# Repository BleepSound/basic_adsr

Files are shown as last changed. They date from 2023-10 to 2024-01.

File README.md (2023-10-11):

# Basic ADSR

Basic ADSR based on René Schmitz [Fastest envelope in the West](https://www.schmitzbits.de/adsr.html). 

Four pots, one input, one output (just what you need).

On switch to change the time constant of the ADSR. I chose some arbitrary values for the capacitors in my case, but if you want different values, you can adjust them to your needs. 

Just change the values of **C8** and **C9**, which can be either polarized electrolytic or unpolarized capacitors. Just make sure you get the orientation right on the polarized ones.

## Schematics

basic ADSR schematic

## BoM

[See bom](documentation/bom/Basic-ADSR_V1.0--iBoM.html)

## Build Informations

Regular build, I use ceramic capacitors but you can use film/polyester.

:warning: When building modules, always do it in this order (from smallest component to highest):
- diodes
- resistors
- DIP chips
- capacitors (film/ceramic)
- Transistors
- Electrolytic capacitors

To solder the headers, place them and place both PCBs in their final position before fully soldering the pin headers/sockets.

For the next parts, always place them without soldering them on: 
- jacks, pots and switches that go throught the front panel

Once placed, put the front panel in place, then fasten all components to it. Once this is done, you can solder all the remaining components.

## Images

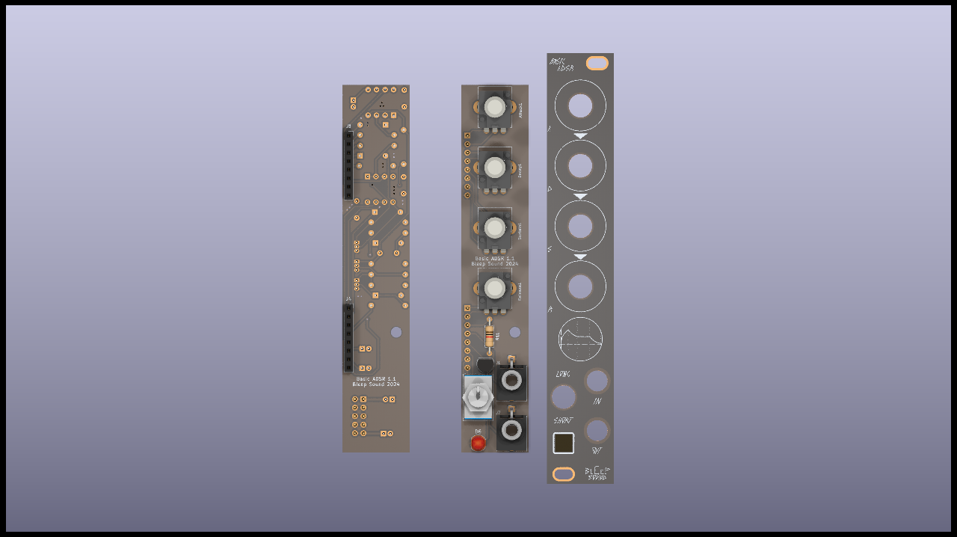
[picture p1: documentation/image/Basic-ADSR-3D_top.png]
3D basic ADSR(front)


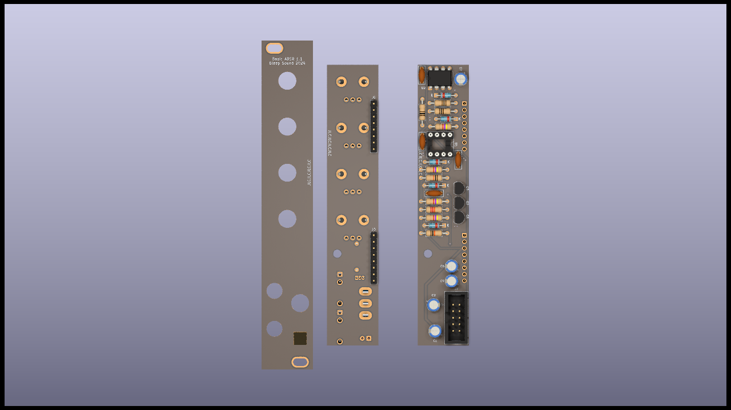
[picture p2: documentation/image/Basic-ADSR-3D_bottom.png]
3D basic ADSR(back)


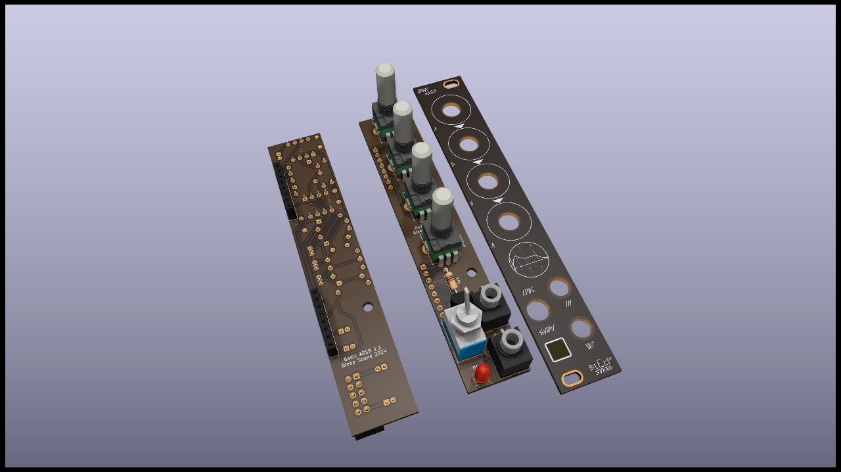
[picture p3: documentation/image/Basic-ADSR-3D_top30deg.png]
3D basic ADSR(iso)


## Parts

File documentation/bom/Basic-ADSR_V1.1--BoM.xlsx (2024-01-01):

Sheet: BoM
Basic-ADSR_V1.1 Bill of Materials
Schematic: | Basic-ADSR | Component Groups: | 23
Variant: | default | Component Count: | 44 (0 SMD/ 44 THT)
Revision: | 1.1 | Fitted Components: | 44 (0 SMD/ 44 THT)
Date: | 2024-01-01 | Number of PCBs: | 1
KiCad Version: | 7.0.7-7.0.7~ubuntu22.04.1 | Total Components: | 44
Row | Description | References | Value | Quantity Per PCB | Comments
1 | Potentiometer | Attack1 Decay1 Release1 | 1M | 3 | Pots
2 | Unpolarized capacitor, small symbol | C5 | 10nF | 1
3 | Unpolarized capacitor, small symbol | C3 C4 C6 | 100nF | 3
4 |  | C8 | 1uF | 1 | Radial electrolytic capacitors, can be changed to any value to change length
5 |  | C9 | 4.7uF | 1 | Radial electrolytic capacitors, can be changed to any value to change length
6 |  | C1 C2 C7 | 10uF | 3 | Radial electrolytic capacitors
7 | Diode | D1 D2 D3 D4 D5 | 1N4148 | 5
8 | Light emitting diode | D6 | Out-LED | 1
9 | Generic connector, single row, 01x08, script generated (kicad-library-utils/schlib/autogen/connector/) | J3 J4 | Conn_Circuit | 2
10 | Generic connector, single row, 01x08, script generated (kicad-library-utils/schlib/autogen/connector/) | J5 J6 | Conn_Jack | 2
11 | Thonkiconn Audio Jack | J1 | In | 1 | Thonkiconn jack
12 | Thonkiconn Audio Jack | J7 | Output | 1 | Thonkiconn jack
13 | Generic connector, single row, 01x10, script generated (kicad-library-utils/schlib/autogen/connector/) | J2 | Power Input | 1
14 | 0.1A Ic, 45V Vce, Small Signal NPN Transistor, TO-92 | Q1 Q2 Q3 Q4 | BC547 (https://www.onsemi.com/pub/Collateral/BC550-D.pdf) | 4 | Can use BC548
15 | Resistor | R7 R8 R10 | 100R | 3
16 | Resistor | R11 | 1k | 1
17 | Resistor | R2 R4 R6 R9 | 4.7k | 4
18 | Resistor | R1 R5 | 10k | 2
19 | Resistor | R3 | 22k | 1
20 | Switch, single pole double throw | SW1 | Length (https://www.taydaelectronics.com/mini-toggle-switch-spdt-on-on.html) | 1 | SPDT On-On Switch
21 | Potentiometer | Sustain1 | 10k | 1 | Pots
22 | Timer, 555 compatible, PDIP-8 | U2 | LM555xN (http://www.ti.com/lit/ds/symlink/lm555.pdf) | 1
23 | Dual Low-Noise JFET-Input Operational Amplifiers, DIP-8/SOIC-8 | U1 | TL072 (http://www.ti.com/lit/ds/symlink/tl071.pdf) | 1

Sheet: Colors
KiCad Fields (default)
Generated Fields
User Fields
Empty Fields

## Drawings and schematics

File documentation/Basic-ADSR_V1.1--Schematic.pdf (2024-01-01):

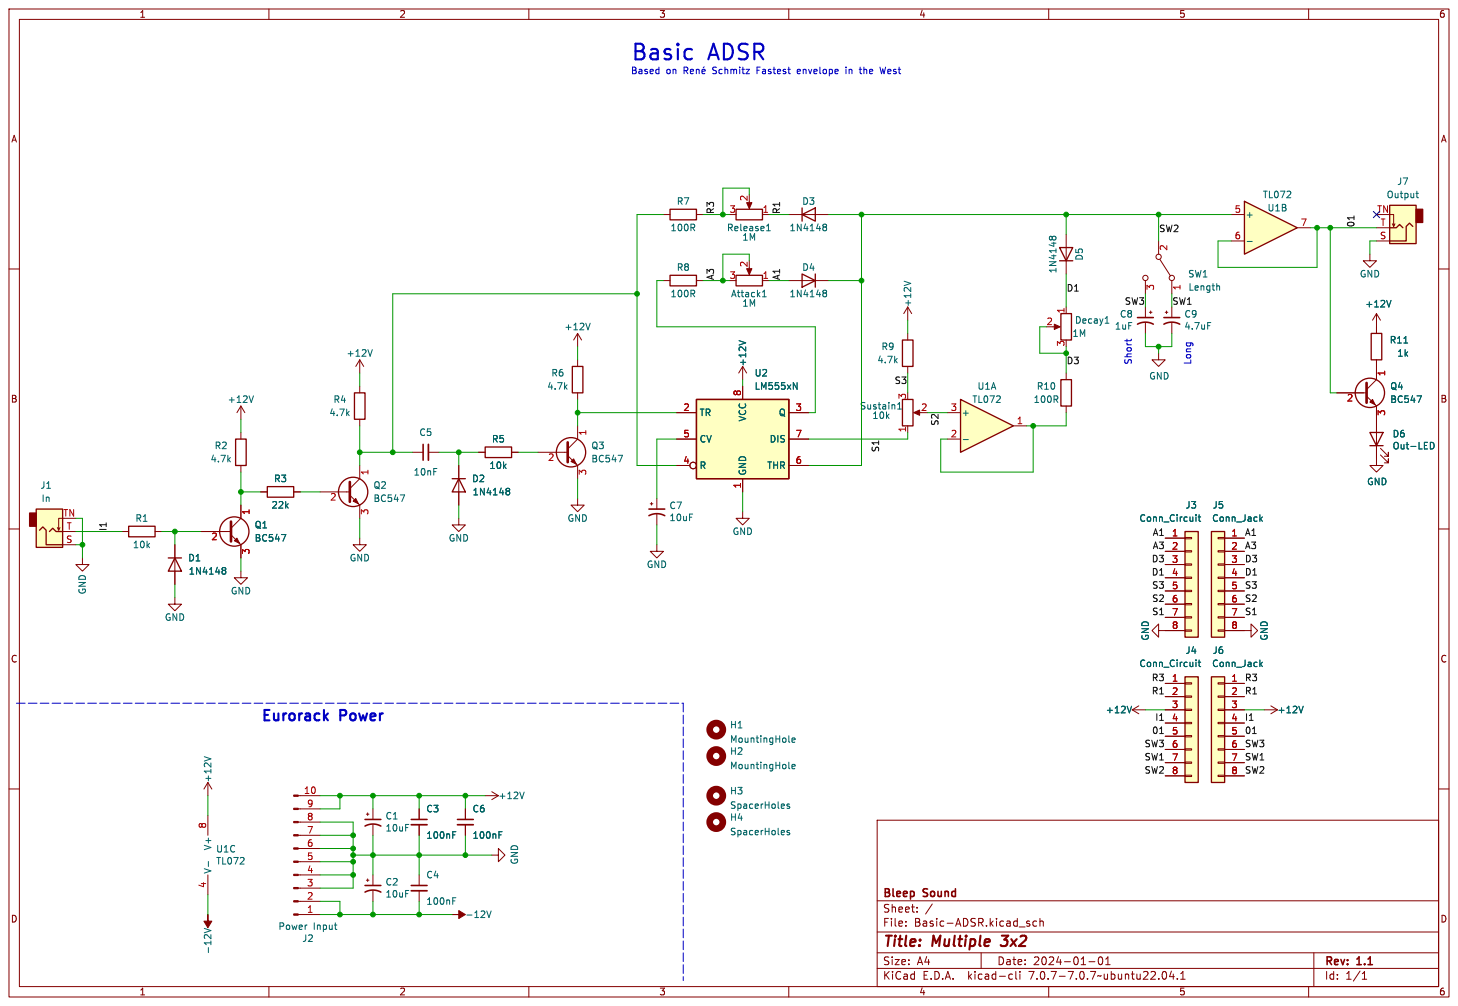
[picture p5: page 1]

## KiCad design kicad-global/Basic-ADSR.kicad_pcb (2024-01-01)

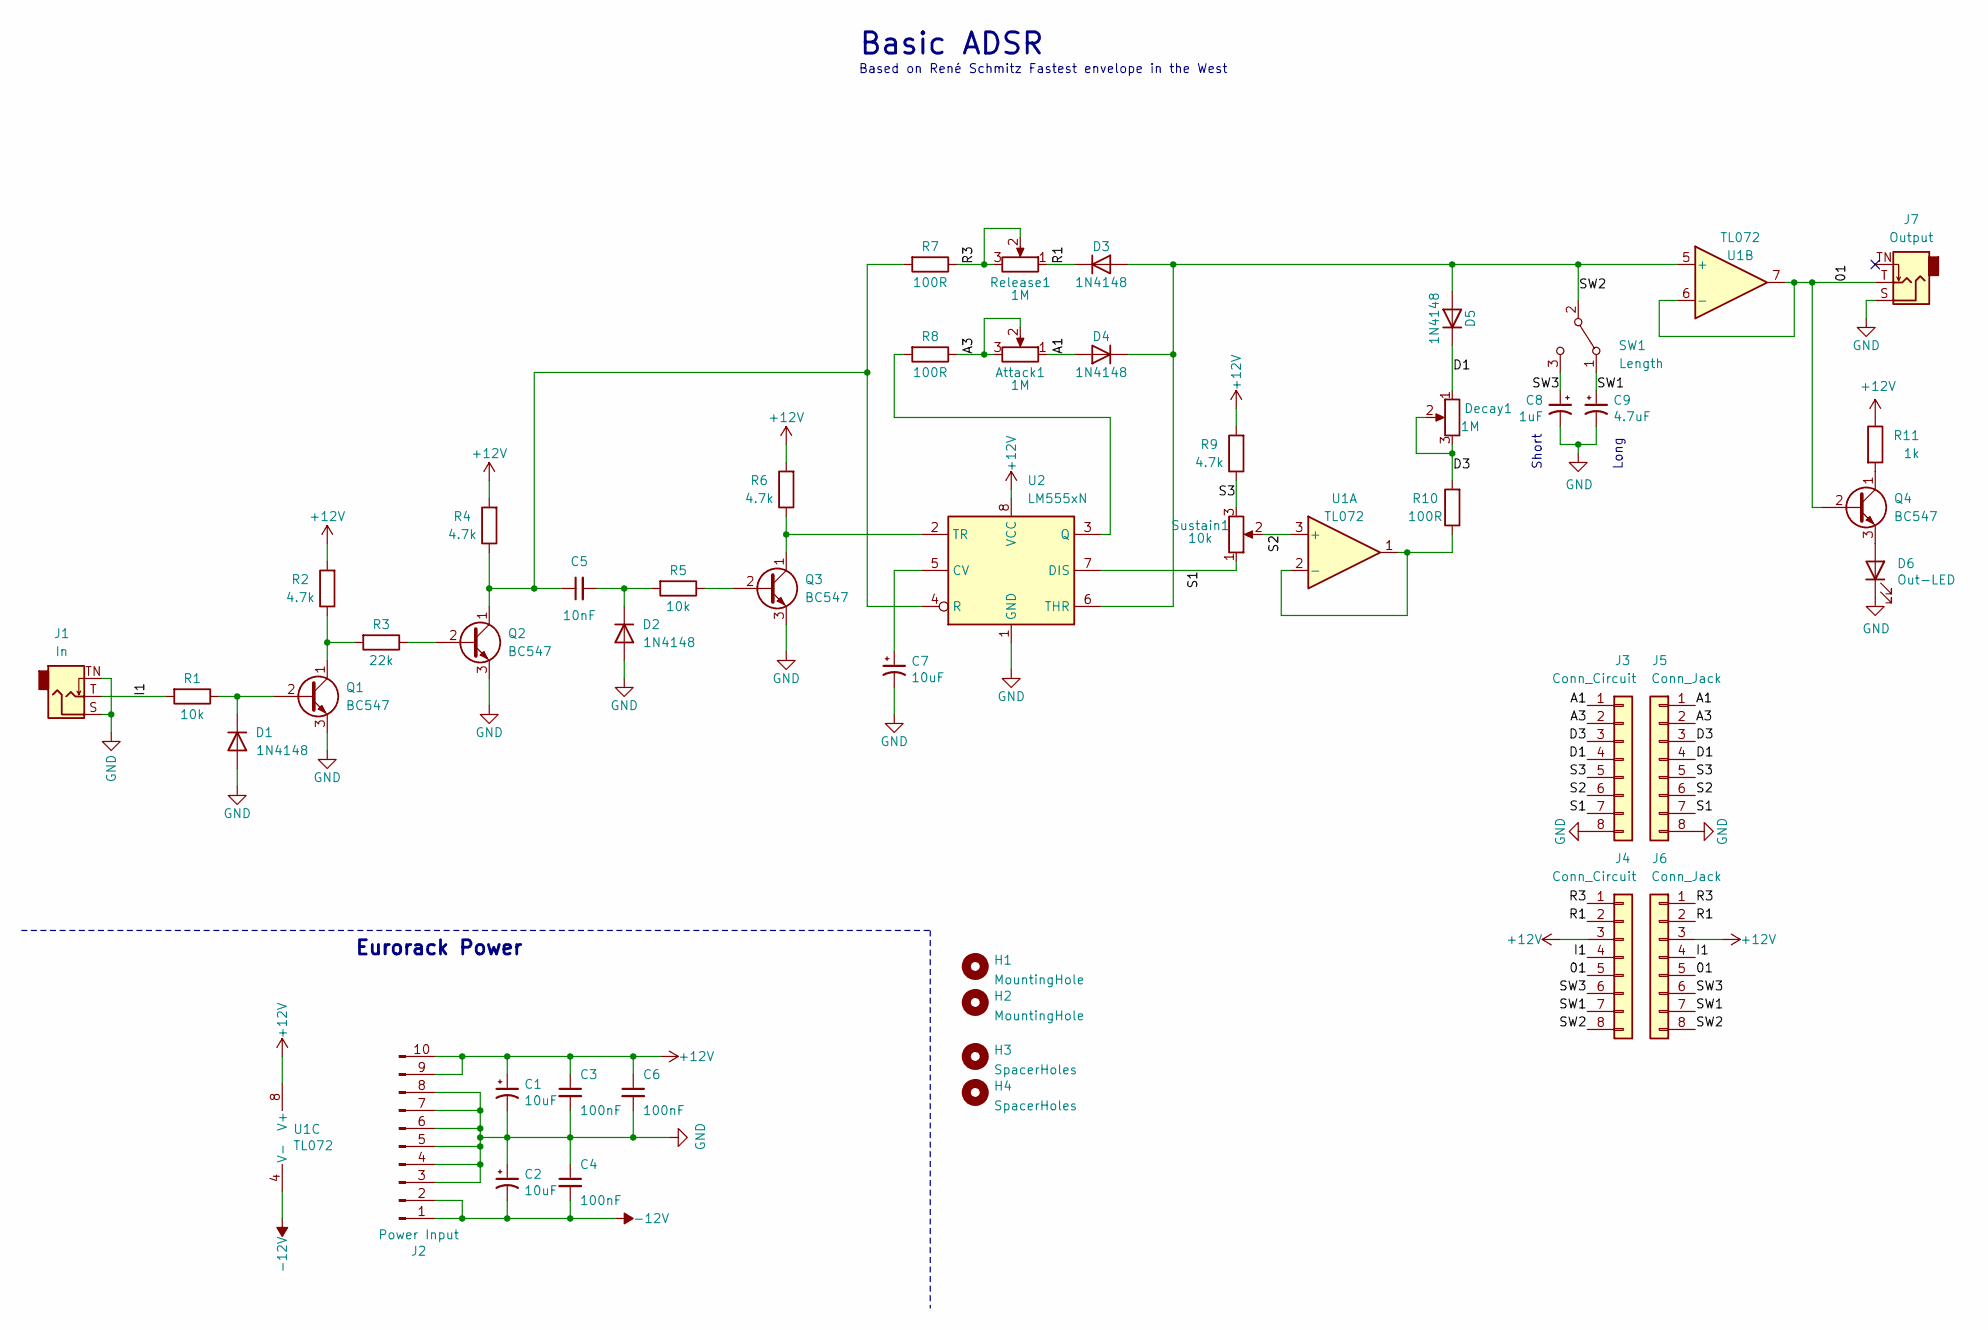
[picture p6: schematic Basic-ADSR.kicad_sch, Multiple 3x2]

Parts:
Attack1: 1M; Pot-bourns-alpha
C1, C2, C7: 10uF; CP_Radial_D5.0mm_P2.00mm
C3, C4, C6: 100nF; C_Disc_D7.0mm_W2.5mm_P5.00mm
C5: 10nF; C_Disc_D7.0mm_W2.5mm_P5.00mm
C8: 1uF; CP_Radial_D5.0mm_P2.00mm
C9: 4.7uF; CP_Radial_D5.0mm_P2.00mm
D1, D2, D3, D4, D5: 1N4148; D_DO-35_SOD27_P7.62mm_Horizontal
D6: Out-LED; LED_D4.0mm
Decay1: 1M; Pot-bourns-alpha
H1, H2: MountingHole; Doepfer Mounting hole
H3, H4: SpacerHoles; MountingHole_3.2mm_M3
J1: In; Thonkiconn
J2: Power Input; IDC-Header_2x05_P2.54mm_Vertical
J3, J4: Conn_Circuit; PinSocket_1x08_P2.54mm_Vertical
J5, J6: Conn_Jack; PinHeader_1x08_P2.54mm_Vertical
J7: Output; Thonkiconn
Q1, Q2, Q3, Q4: BC547; TO-92_Inline
R1, R5: 10k; R_Axial_DIN0207_L6.3mm_D2.5mm_P10.16mm_Horizontal
R2, R4, R6, R9: 4.7k; R_Axial_DIN0207_L6.3mm_D2.5mm_P10.16mm_Horizontal
R3: 22k; R_Axial_DIN0207_L6.3mm_D2.5mm_P10.16mm_Horizontal
R7, R8, R10: 100R; R_Axial_DIN0207_L6.3mm_D2.5mm_P10.16mm_Horizontal
R11: 1k; R_Axial_DIN0207_L6.3mm_D2.5mm_P10.16mm_Horizontal
Release1: 1M; Pot-bourns-alpha
SW1: Length; SW_Toggle_Blue_wSlots
Sustain1: 10k; Pot-bourns-alpha
U1: TL072; DIP-8_W7.62mm_Socket
U2: LM555xN; DIP-8_W7.62mm

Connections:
+12V: C1.1, C3.1, C6.1, J2.9, J2.10, J4.3, J6.3, R2.2, R4.2, R6.2, R9.2, R11.1, U1.8 (V+), U2.8 (VCC)
-12V: C2.2, C4.2, J2.1, J2.2, U1.4 (V-)
/01: J4.5, J6.5, J7.T, Q4.2 (B), U1.6 (-), U1.7
/A1: Attack1.1, D4.2 (A), J3.1, J5.1
/A3: Attack1.2, Attack1.3, J3.2, J5.2, R8.1
/D1: D5.1 (K), Decay1.1, J3.4, J5.4
/D3: Decay1.2, Decay1.3, J3.3, J5.3, R10.2
/I1: J1.T, J4.4, J6.4, R1.2
/R1: D3.1 (K), J4.2, J6.2, Release1.1
/R3: J4.1, J6.1, R7.1, Release1.2, Release1.3
/S1: J3.7, J5.7, Sustain1.1, U2.7 (DIS)
/S2: J3.6, J5.6, Sustain1.2, U1.3 (+)
/S3: J3.5, J5.5, R9.1, Sustain1.3
/SW1: C9.1, J4.7, J6.7, SW1.1 (A)
/SW2: D3.2 (A), D4.1 (K), D5.2 (A), J4.8, J6.8, SW1.2 (B), U1.5 (+), U2.6 (THR)
/SW3: C8.1, J4.6, J6.6, SW1.3 (C)
GND: C1.2, C2.1, C3.2, C4.1, C6.2, C7.2, C8.2, C9.2, D1.2 (A), D2.2 (A), D6.1 (K), J1.S, J1.TN, J2.3, J2.4, J2.5, J2.6, J2.7, J2.8, J3.8, J5.8, J7.S, Q1.3 (E), Q2.3 (E), Q3.3 (E), U2.1 (GND)
unnamed: D1.1 (K), Q1.2 (B), R1.1
unnamed: C5.2, D2.1 (K), R5.2
unnamed: D6.2 (A), Q4.3 (E)
unnamed: Q1.1 (C), R2.1, R3.2
unnamed: Q2.2 (B), R3.1
unnamed: C5.1, Q2.1 (C), R4.1, R7.2, U2.4 (R)
unnamed: Q3.2 (B), R5.1
unnamed: Q3.1 (C), R6.1, U2.2 (TR)
unnamed: Q4.1 (C), R11.2
unnamed: R10.1, U1.1, U1.2 (-)
unnamed: C7.1, U2.5 (CV)
unnamed: R8.2, U2.3 (Q)

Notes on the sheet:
Based on René Schmitz Fastest envelope in the West
Long
Basic ADSR
Eurorack Power
Short

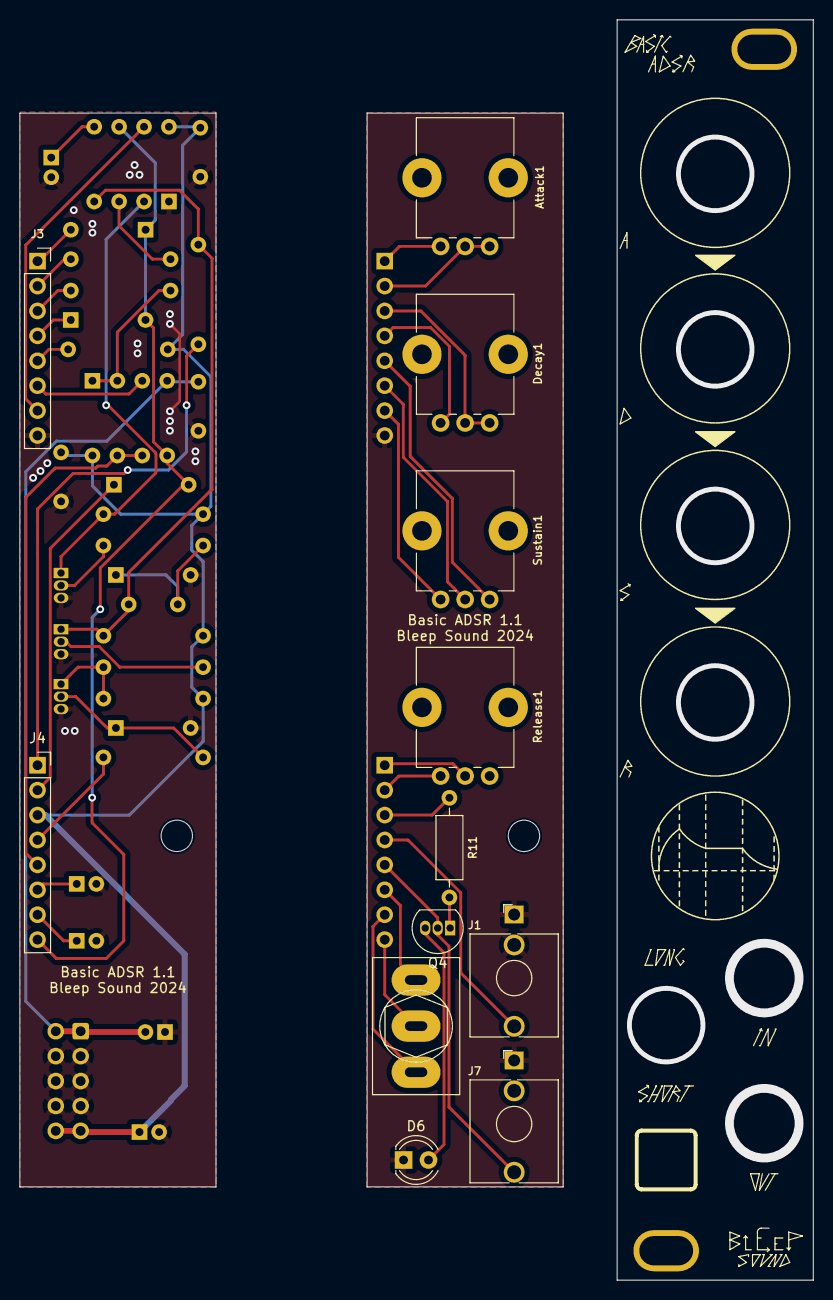
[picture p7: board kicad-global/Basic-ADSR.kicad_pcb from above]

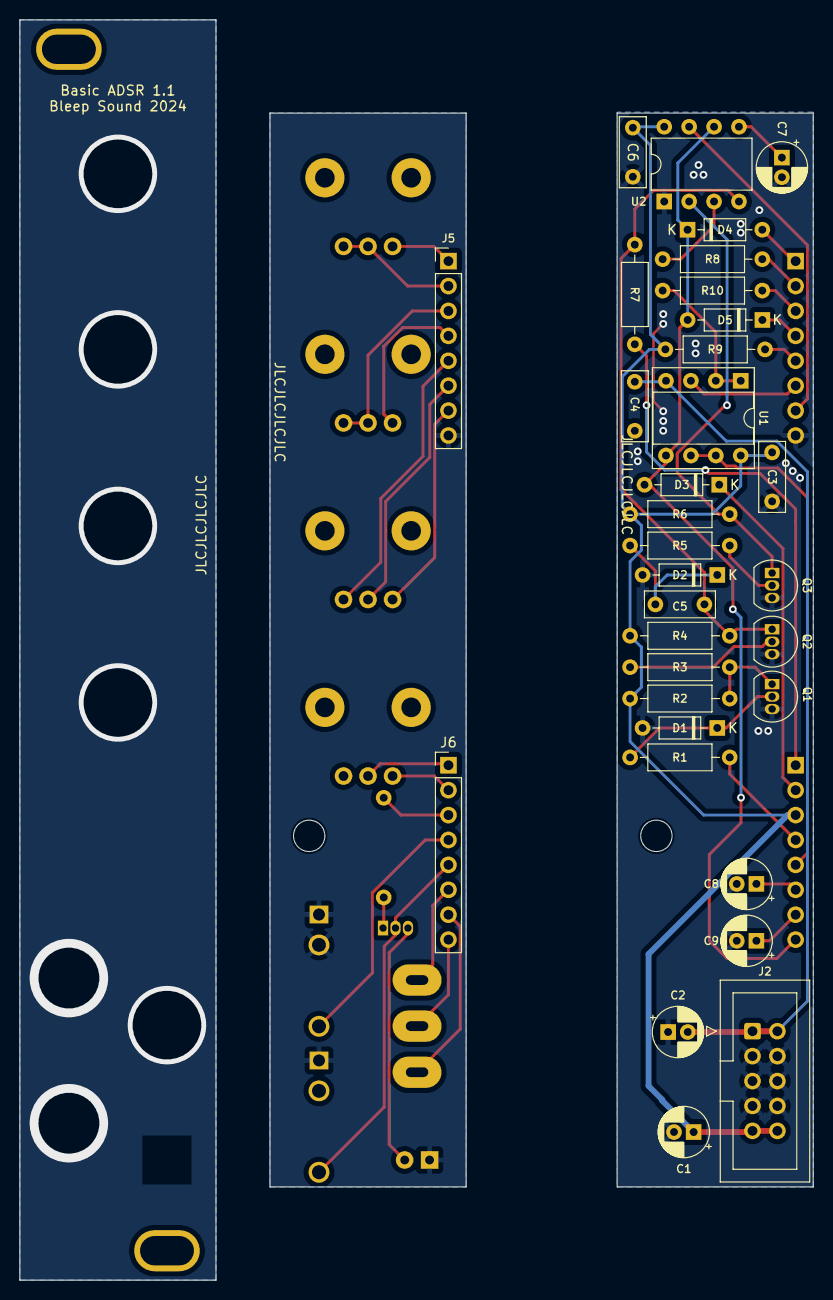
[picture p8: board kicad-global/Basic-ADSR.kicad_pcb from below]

Board: 2 copper layers, 80.9 x 128.5 mm, 48 parts (32 on the bottom side), 29 nets.

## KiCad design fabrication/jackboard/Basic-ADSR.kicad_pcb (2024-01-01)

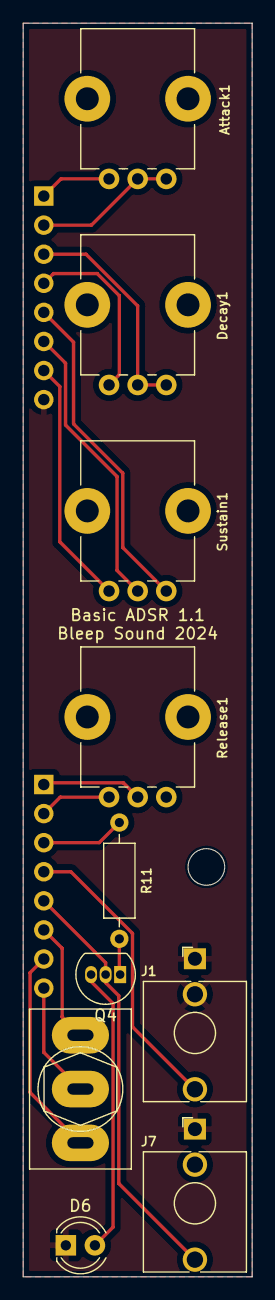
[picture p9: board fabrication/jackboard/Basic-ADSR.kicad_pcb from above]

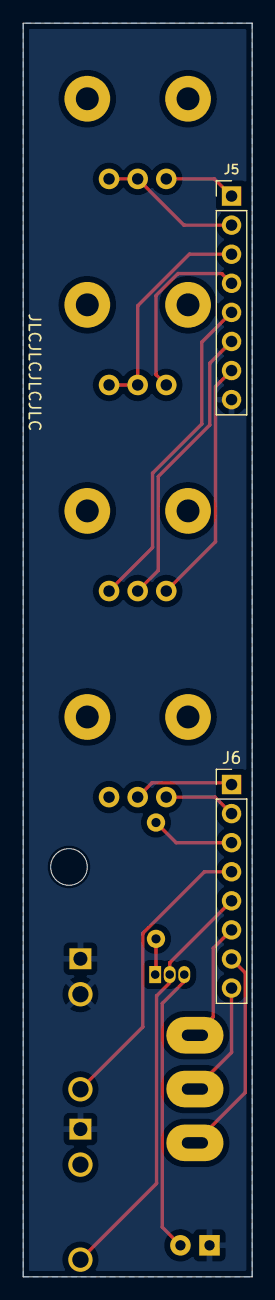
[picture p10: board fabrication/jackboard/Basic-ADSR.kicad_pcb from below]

Board: 2 copper layers, 20.0 x 109.5 mm, 13 parts (2 on the bottom side), 18 nets.

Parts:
Attack1: 1M; Pot-bourns-alpha
D6: Out-LED; LED_D4.0mm
Decay1: 1M; Pot-bourns-alpha
H3: SpacerHoles; MountingHole_3.2mm_M3
J1: In; Thonkiconn
J5, J6: Conn_Jack; PinHeader_1x08_P2.54mm_Vertical
J7: Output; Thonkiconn
Q4: BC547; TO-92_Inline
R11: 1k; R_Axial_DIN0207_L6.3mm_D2.5mm_P10.16mm_Horizontal
Release1: 1M; Pot-bourns-alpha
SW1: Length; SW_Toggle_Blue_wSlots
Sustain1: 10k; Pot-bourns-alpha

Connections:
+12V: J6.3, R11.1
/01: J6.5, J7.T, Q4.2 (B)
/A1: Attack1.1, J5.1
/A3: Attack1.2, Attack1.3, J5.2
/D1: Decay1.1, J5.4
/D3: Decay1.2, Decay1.3, J5.3
/I1: J1.T, J6.4
/R1: J6.2, Release1.1
/R3: J6.1, Release1.2, Release1.3
/S1: J5.7, Sustain1.1
/S2: J5.6, Sustain1.2
/S3: J5.5, Sustain1.3
/SW1: J6.7, SW1.1 (A)
/SW2: J6.8, SW1.2 (B)
/SW3: J6.6, SW1.3 (C)
GND: D6.1 (K), J1.S, J1.TN, J5.8, J7.S
unnamed: D6.2 (A), Q4.3 (E)
unnamed: Q4.1 (C), R11.2

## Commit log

2023-09-25 Full kicad files + fab files + Doc for ADSR
    [Basic-ADSR--NPTH_map.gbr, Basic-ADSR--PTH_map.gbr, Basic-ADSR-B_Cu.gbl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]
2023-10-11 update 3D view
    [Basic-ADSR.kicad_pcb]
2024-01-01 update GND plane for circuitboard following issues
    [Basic-ADSR--NPTH_map.gbr, Basic-ADSR--PTH_map.gbr, Basic-ADSR-B_Cu.gbl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]
